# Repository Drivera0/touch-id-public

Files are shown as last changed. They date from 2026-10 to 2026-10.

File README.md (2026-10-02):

# Whorl Touch: a fingerprint knob for the NuPhy Air75 V3

A drop-in fingerprint-authentication module that replaces the knob in the
top-right corner of a **NuPhy Air75 V3**. Touch it and it confirms your identity
to the paired computer wirelessly, without a $149 Touch ID keyboard.

> [!WARNING]
> **Work in progress.** The design is finished on screen, but nothing has been
> proven on real hardware yet. The main PCB hasn't been ordered or built yet,
> the firmware hasn't been built or run on the board, and none of it has been
> tested end to end. See [Project status](#project-status) for exactly where
> things stand.

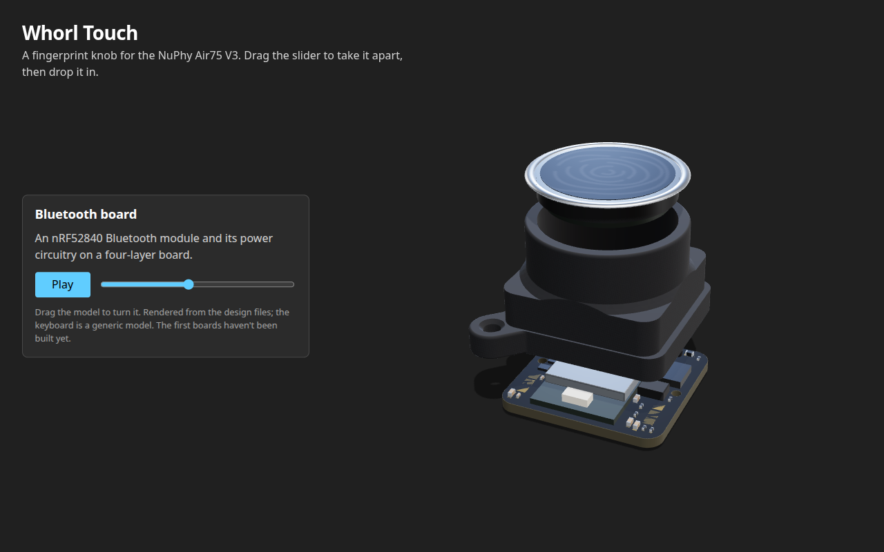
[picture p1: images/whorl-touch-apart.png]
Whorl Touch taken apart, from the interactive 3D model


**[Open the interactive 3D model](https://drivera0.github.io/whorl-touch-public/)**:
drag to turn it, slide to take it apart
([or open it already apart](https://drivera0.github.io/whorl-touch-public/?at=0.45)),
then watch it drop into the keyboard.

This repo is the project's public face: the story of how it was designed, and
a 3D model of the module. **[JOURNEY.md](JOURNEY.md)** tells the story; the
design files themselves are private.

## The problem

- The Air75 V3 runs NuPhy's closed firmware (no QMK), so the keyboard can't be
  taught about a sensor. The module is an **independent sidecar**: it uses the
  knob slot as a mount and does its own sensing, crypto and radio.
- The slot supplies **no power**, so the module harvests its own energy and
  runs from a protected 77 mAh coin cell.
- The board is a small 4-layer design around an nRF52840 module, with a
  fingerprint sensor above it in a printed nylon housing.

## Project status

*Last updated September 2026.*

```mermaid
flowchart TB
  subgraph S1["1 · Design"]
    direction LR
    A["Research &<br/>teardown"] --> B["Architecture"] --> C["PCB design<br/>v2 → v7"] --> E["Fab package"]
    D["Housing design"] --> F["Housings<br/>printed"]
  end
  subgraph S2["2 · Build"]
    direction LR
    G["Flashing<br/>fixture"] --> H["Main PCB made<br/>& assembled"] --> I["Bring-up &<br/>power tests"]
  end
  subgraph S3["3 · Prove it works"]
    direction LR
    J["Firmware on<br/>real hardware"] --> K["Fingerprint match<br/>end to end"] --> L["Mac / Windows<br/>helper apps"]
  end
  subgraph S4["4 · Next"]
    direction LR
    M["USB dongle"]
  end
  S1 --> S2 --> S3 --> S4

  classDef done fill:#2da44e,stroke:#1a7f37,color:#fff
  classDef doing fill:#d4a72c,stroke:#9a6700,color:#000
  classDef todo fill:#eaeef2,stroke:#8c959f,color:#24292f
  class A,B,C,D,E,F done
  class G doing
  class H,I,J,K,L,M todo
```

Green = done, yellow = in progress, grey = not started.

| Stage | Status | Notes |
|---|---|---|
| Research and keyboard teardown | Done | Every slot contact characterised by measurement (method and results private) |
| Architecture | Done | Independent sidecar, harvests its own energy, protected coin cell |
| PCB design | Done (on screen) | v7 passes all 22 pre-order checks and DRC. Never built. |
| Housing | Printed | Both housing variants printed in MJF nylon and look good. Not yet fitted with a real board. |
| Fab package | Ready | Gerbers, BOM and placement verified against each other |
| Flashing fixture | In progress | The first printed pogo-pin jig failed, so it's being replaced by a custom carrier PCB and a 3D-printed flash frame. |
| Main PCB | Not ordered yet | Design and fab files are ready; it gets ordered once all the parts are in hand |
| Bring-up and power tests | Not started | Needs a built board |
| Firmware | Not started on hardware | Architecture and protocols are designed. The firmware hasn't been built for or run on a real board. The source is closed; see [firmware/](firmware/README.md). |
| Fingerprint matching end to end | Not started | |
| Host apps (Mac / Windows) | Prototype | Early helper-app experiments; not tested with a real module |
| USB dongle | Design study | Size and module trade studies done |

## What's here

| Path | What's in it |
|---|---|
| `JOURNEY.md` | How the design got built, milestone by milestone |
| `docs/` | The interactive 3D model, served by GitHub Pages |
| `firmware/` | A pointer: the source is closed, binaries come as Releases |
| `THIRD-PARTY-NOTICES.md` | Credits and licences for third-party work |

## Not in this repo

The files needed to build the product are private:

- Board source and fab files, board renders, and the flashing fixture
- The keyboard-slot work: how it was mapped, what each contact carries, the
  measurements and the design docs that record them
- The housing and board generators, and the engineering notes and design docs
- Firmware and helper-app source code
- Vendor datasheets (copyrighted), supplier quotes and contact details

## Tools

KiCad 10, Altium (cross-check), CadQuery, Python, Zephyr on nRF52840,
JLCPCB PCBA and MJF nylon printing.

## Credits and license

Inspired by [tinyTouch](https://github.com/ZimengXiong/tinyTouch) by Zimeng Xiong and by
[YubiKey](https://www.yubico.com/products/).

Everything else: **© 2026 Driver. All rights reserved.** You're welcome to
read it and learn from it. Please ask before reusing it.

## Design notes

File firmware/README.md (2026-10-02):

# Firmware

The firmware for the knob (Zephyr RTOS on the nRF52840) is **closed source**
and isn't in this repository.

- **Prebuilt firmware** will be published as `.hex` files under this repo's
  [Releases](https://github.com/Drivera0/whorl-touch-public/releases) once it has run on real hardware. Each release
  includes `SHA256SUMS` so you can check the download.

Status: not yet built for or run on a real board. See
[Project status](../README.md#project-status).

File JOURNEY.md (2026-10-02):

# The journey: how the board got built

> **Still a work in progress.** Everything below is design work. The board
> hasn't been manufactured or tested yet, and the firmware hasn't run on real
> hardware. See [Project status](README.md#project-status).
>
> The design files, board renders and keyboard-slot measurements stay
> private. Every commit is here with its message, but without the private
> files, and messages that would give away the slot contacts are reworded. The module is public as an
> [interactive 3D model](https://drivera0.github.io/whorl-touch-public/).

How the design got built, milestone by milestone. Each milestone is a
[git tag](https://github.com/Drivera0/whorl-touch-public/tags); click a commit
to read its message.

Whorl Touch taken apart, from the interactive 3D model

---

## 1. Salvage the first board (Aug 20): `m01` → `m02`

The first design was an ESP32-C3 board drawn in Altium. Before changing
anything, it got imported into KiCad and checked against the original.

- [Import the Altium board into KiCad, verified exact](https://github.com/Drivera0/whorl-touch-public/commit/c0a0e6f)
- [Nine orphan `)` made the board file unparseable](https://github.com/Drivera0/whorl-touch-public/commit/6b71473), so a syntax gate was added and has run on every edit since
- [Every land pattern traced back to its vendor drawing](https://github.com/Drivera0/whorl-touch-public/commit/d55f322), which found errors on U1, U2 and C3/C4

**Lesson:** a footprint you haven't traced to a datasheet is a guess.

## 2. The master spec and the v3 rebuild (Aug 26 – 27): `m03` → `m05`

The ESP32 was too wide for the slot. The rebuild moved to a BLE-only nRF52840
module on a 4-layer board, and one design spec became the single source of
truth (it stays private).

- The design spec becomes the master file
- [pcb-v3 built: 4 layers, 177 pads, all three checkers pass](https://github.com/Drivera0/whorl-touch-public/commit/d357334)
- [Two checker bugs, including KiCad's Y-down rotation sign (79 phantom shorts)](https://github.com/Drivera0/whorl-touch-public/commit/fc8540c)
- [U2's land was 0.25 mm off its own centreline](https://github.com/Drivera0/whorl-touch-public/commit/b953dad)
- [The "open connections" metric was lying](https://github.com/Drivera0/whorl-touch-public/commit/37f3c16). A net with zero copper never showed as disconnected, so deleting a net scored as a win.
- [Zero open connections, 15/15 preflight checks](https://github.com/Drivera0/whorl-touch-public/commit/84c035e)

**Lesson:** when a check fails, suspect the checker first. It was wrong more
often than the board.

## 3. "The board had no ground" (Aug 28): `m06` → `m07`

- [THE BOARD HAD NO GROUND](https://github.com/Drivera0/whorl-touch-public/commit/1692c54). Every check passed, and none of them looked for it. The ground pour went in, and a gate was added so it can't happen again.
- [KiCad 10 changed the file format and every parser went blind](https://github.com/Drivera0/whorl-touch-public/commit/eca1690)
- Altium's DRC found a real defect the KiCad checks couldn't see. The board was then re-imported clean.
- [The pick-and-place file was in the wrong coordinate space](https://github.com/Drivera0/whorl-touch-public/commit/34131c6)
- A housing corner wall was 0.15 mm, not 0.8

**Lesson:** cross-check with a second, independent tool.

## 4. Choosing the cell (Aug 28): `m08`

The module needs stored energy, and nothing that fits the cavity is simple.

- [The CP1254 "IP Wires" is not protected and doesn't fit](https://github.com/Drivera0/whorl-touch-public/commit/47fa22a)
- [The charge limit is 4.30 V, not 4.00 (a misread footnote)](https://github.com/Drivera0/whorl-touch-public/commit/97d280d)
- [Cell decided: LiPol LPM1254 with a factory PCM and wires](https://github.com/Drivera0/whorl-touch-public/commit/689705c)
- [Sensor: the ZW0905 was discontinued; the HLK-ZW0922 is a drop-in](https://github.com/Drivera0/whorl-touch-public/commit/5e64939)

## 5. The long routing fight (Aug 29 – 30): `m09` → `m10`

Adding a protection IC to a 20 × 19 mm board started two days of placement,
routing and ground-pour work.

- [My "it doesn't fit" result was a fourth scanner bug](https://github.com/Drivera0/whorl-touch-public/commit/935eb35)
- Slot depth was never a constraint: the module stands proud by design
- Reverted three hand-placed ground taps, all of them faulty
- [pour_truth.py judges connectivity against the fill KiCad actually computed](https://github.com/Drivera0/whorl-touch-public/commit/8d3021e), not a model of it
- [Both press-fit pins had been drilled through copper](https://github.com/Drivera0/whorl-touch-public/commit/9170b3f)
- [Custom pads: `(size)` is the anchor, not the copper, so every parser read 3× low](https://github.com/Drivera0/whorl-touch-public/commit/6880130)
- [Rejected a smaller module (BC840M), because it needs a larger board](https://github.com/Drivera0/whorl-touch-public/commit/a3a3f36)
- v5: DRC clean, then [v6: zero open pads, zero blockers](https://github.com/Drivera0/whorl-touch-public/commit/0410f94)

**Lesson:** a smaller part isn't always a smaller board. Ceramic-antenna
modules need less keep-out than trace-antenna ones.

## 6. v7 and release (Aug 31 – Sep 1): `m11` → `m13`

- [The protected cell was confirmed, so the on-board PCM was deleted](https://github.com/Drivera0/whorl-touch-public/commit/946cf8b). That removed four parts and healed the last stranded pad.
- `m11`: preflight at 0 blockers, 0 open pads, ground fully connected. The v7 board files are private.
- [Pogo-pin flashing jig](https://github.com/Drivera0/whorl-touch-public/commit/e7efebc)
- [Housing v6.5 after JLC's DFM review](https://github.com/Drivera0/whorl-touch-public/commit/0dcda58)

## 7. Firmware and the product direction (Aug 31 – Sep 1)

The firmware history is merged in: Zephyr on the nRF52840, the sensor driver,
the auth crypto and the helper apps. The design docs and the source
code stay private.

- [Gut the ESP32 fork and start the nRF52840 Zephyr firmware for pcb-v7](https://github.com/Drivera0/whorl-touch-public/commit/d6a3725)
- [LESC-only pairing, HMAC challenge-response and a hash ratchet](https://github.com/Drivera0/whorl-touch-public/commit/f7243ab)
- [Mac keycard proven: `sudo` authenticates by smart card, gated on a touch](https://github.com/Drivera0/whorl-touch-public/commit/2de955a)
- [A smart card you can't remove is a lockout, so that got fixed](https://github.com/Drivera0/whorl-touch-public/commit/2353bb1)
- [Knob-to-dongle transport: proprietary 2.4 GHz (ESB), not BLE](https://github.com/Drivera0/whorl-touch-public/commit/f0d7535)
- [Product pivot: FIDO2 is the core of the product](https://github.com/Drivera0/whorl-touch-public/commit/5d12048)

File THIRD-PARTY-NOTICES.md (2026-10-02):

# Third-party notices

Whorl Touch includes or credits the work below. Each release ships this file.

## tinyTouch

Whorl Touch was inspired by tinyTouch (https://github.com/ZimengXiong/tinyTouch).
Its notice is included here as a courtesy and so that any question is settled.

```
MIT License

Copyright (c) 2026 Zimeng Xiong

Permission is hereby granted, free of charge, to any person obtaining a copy
of this software and associated documentation files (the "Software"), to deal
in the Software without restriction, including without limitation the rights
to use, copy, modify, merge, publish, distribute, sublicense, and/or sell
copies of the Software, and to permit persons to whom the Software is
furnished to do so, subject to the following conditions:

The above copyright notice and this permission notice shall be included in all
copies or substantial portions of the Software.

THE SOFTWARE IS PROVIDED "AS IS", WITHOUT WARRANTY OF ANY KIND, EXPRESS OR
IMPLIED, INCLUDING BUT NOT LIMITED TO THE WARRANTIES OF MERCHANTABILITY,
FITNESS FOR A PARTICULAR PURPOSE AND NONINFRINGEMENT. IN NO EVENT SHALL THE
AUTHORS OR COPYRIGHT HOLDERS BE LIABLE FOR ANY CLAIM, DAMAGES OR OTHER
LIABILITY, WHETHER IN AN ACTION OF CONTRACT, TORT OR OTHERWISE, ARISING FROM,
OUT OF OR IN CONNECTION WITH THE SOFTWARE OR THE USE OR OTHER DEALINGS IN THE
SOFTWARE.
```

## KiCad routing tools

`tools/com_github_drandyhaas_kicadroutingtools` is © drandyhaas, MIT
licensed; its full text is in that folder's `LICENSE`.

## Still to list before the first release

The libraries built into the firmware and apps (Zephyr and MCUboot under
Apache 2.0, Nordic nrfx under BSD-3-Clause, the .NET runtime under MIT,
and each app's packages), each with its licence text.

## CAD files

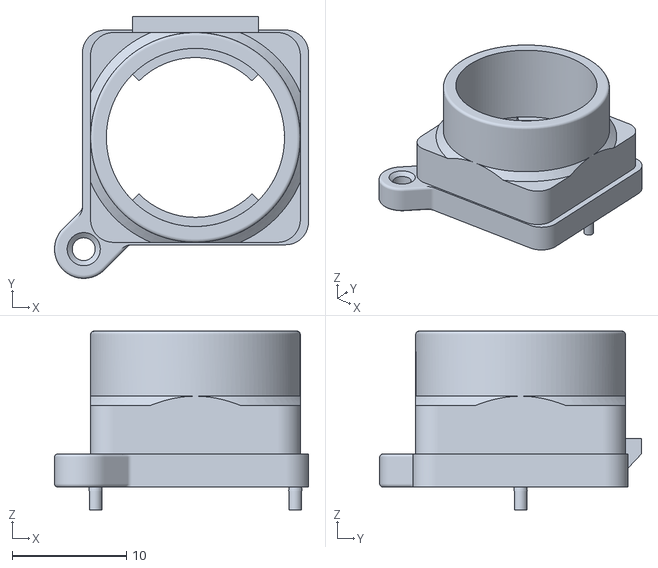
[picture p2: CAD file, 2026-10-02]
docs/housing.stl
22.2 x 22.9 x 15.7

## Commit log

2026-08-20 Baseline: TouchID module as it stands before the U2 land pattern fix
    State captured here:
    cad/pcb-initial-failure/ the design that went to JLCPCB as order [order #] / Y6.
    gerbers-as-ordered/ is MD5-identical to the files JLCPCB received.
    U1 (ESP32-C3-MINI-1) land pattern is CORRECT: 61 pads, 48 perimeter on
    0.8 mm pitch, 1.45 mm thermal grid, 0.7 mm corners, antenna oriented
    away from the pogo pads.
    U2 (TPS7A2033, X2SON-4) land pattern is WRONG: signal pads at
    +/-0.520/+/-0.520 instead of +/-0.421/+/-0.325, thermal 0.55 unrotated
    instead of 0.48 rotated 45 deg, and no solder mask dam.
    cad/pcb-v2/ byte-identical copy of the above, the working f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
2026-08-20 Import the Altium board into KiCad, verified exact
    KiCad 10 File > Import > Non-KiCad Board File on pcb-v2.PcbDoc, saved as
    pcb-v2.kicad_pcb. Layer mapping auto-matched except Edge.Cuts, which
    auto-match sent to Margin; corrected to Edge.Cuts by hand.
    Import result: 96 pads, 184 track segments, 15 vias, 9 nets, 0 unrouted.
    Two footprints: touchid:touchid_board and Espressif:ESP32-C3-MINI-1, so U1
    is a real component with pads 1-53 rather than loose copper.
    VERIFICATION: every one of the 80 SMD pads in the ordered Gerber's top paste
    layer has an exact counterpart in the imported board, max position error
    0.0000 mm, under the transform recorded in cad/pcb-v2/COORDINATE-MAP.txt.
    The importer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
2026-08-20 Fix U2 land pattern (TPS7A2033DQNR, LCSC C46459900, X2SON-4)
    The single real defect on the ordered board. Five pads edited, nothing else
    touched: no tracks, vias, other pads or footprints changed.
    before after
    U2-1..4 0.30 x 0.30 at +-0.520 0.36 x 0.30 at +-0.421 / +-0.325
    U2-5 0.55 sq, no rotation 0.48 sq, ROTATED 45 deg
    all five solder_mask_margin 0 solder_mask_margin -0.05
    Geometry from JLCPCB/LCSC's own footprint for C46459900, cross-checked
    against TI package drawing DQN0004A 4215302/E. Coordinates converted through
    the Y-mirror recorded in COORDINATE-MAP.txt.
    VERIFIED after the edit:
    positions all five land e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
2026-08-20 WIP: U2 pads moved, local routing NOT yet corrected - board has a short
    DO NOT PLOT GERBERS FROM THIS COMMIT.
    Contains:
    - U2 land pattern corrected (commit 98c9e5e, verified correct)
    - U1 pin 5 (GPIO2) tied to +3V3 by a 0.668 mm stub, 0.473 mm clearance, OK
    - check_board.py, a geometry checker that honours pad SHAPE
    KNOWN BROKEN: moving U2's pads by ~0.2 mm left the existing tracks where they
    were, drawn to the old pad positions. Result:
    SHORT U2-1 (+3V3) touching a GND track 0.0000 mm
    tight U2-5 (GND) vs a VBAT track 0.0970 mm
    tight U2-3 (VBAT) vs a GND track 0.1140 mm
    The escape corridors around a 1x1 X2SON are under 0.5 mm, so the local tracks
    need re-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
2026-08-20 Re-route U2's escape for the new pad positions; short resolved
    Deleted 9 tracks that were drawn to U2's OLD pad centres and replaced them
    with 7 at 0.15 mm, which is what fits the escape corridors around a 1x1
    X2SON. The 0.254 mm board default physically does not: the gap between
    U2-1 and U2-4 is 0.482 mm and a 0.254 track needs 0.508 mm with clearance.
    GND U2-5 south escape between U2-1 and U2-4, then to the existing net
    GND U2-2 to U2-5, and U2-2 west to the existing GND branch
    VBAT in to U2-3, down to U2-4 at x=141.46 clear of the U2-5 diamond,
    back out to the VBAT branch
    +3V3 in to U2-1
    RESULT
    before: SHORT U2-1(+3V3) to a GND track 0.0000, plus 0.0970 and 0.114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
2026-08-20 Route U1-22 (GPIO8) to +3V3; both strapping pins now tied high
    GPIO8 had no +3V3 within 4.648 mm and needed a real route, unlike GPIO2 which
    had a 0.668 mm stub available. Written a grid router (route_one.py) rather
    than eyeballing coordinates: it builds an obstacle map from the real copper
    honouring pad SHAPE, inflates by clearance + half trace width, and A*-searches
    F.Cu/B.Cu with vias. It returns nothing rather than something illegal.
    Route: 4 segments at 0.15 mm + 3 vias, pin 22 -> B.Cu -> F.Cu -> B.Cu -> the
    +3V3 branch near (145.45, 105.05). Three vias because B.Cu is genuinely
    blocked between y 102.7 and 104.95 at that x; raising the via cost from 0.6 to
    3.0 did not reduce it, which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
2026-08-20 Repair 9 orphan ')' that made the board file unparseable; add a syntax gate
    Found while saving the board: the file had 9 more closing parens than opening
    ones. KiCad would have refused to open it, and it would never have plotted.
    Cause: my track deletion in bd6b0d5 (the U2 re-route) removed each segment
    block's contents but left its final ')' behind, 9 times. Introduced there,
    not by the pin 22 route.
    Why nothing caught it: check_board.py and check_connect.py both read the board
    with REGEX. Regex finds the blocks it is looking for and ignores everything
    else, so both kept reporting a clean, fully connected board. Every clearance
    and connectivity number they printed was correct. The file wa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
2026-08-20 Add HANDOFF.md; commit the JLCPCB production file and the routing/check scripts
    HANDOFF.md covers cad/pcb-v2 only: what is fixed, what is open and ranked, the
    coordinate transform, the verification workflow, and the eight traps that have
    each produced a confident wrong answer at least once.
    New finding from diffing against production-file-old-version.zip: U1's chamfered
    thermal pad is misplaced by exactly (1.45, 1.45) in the KiCad import. The ordered
    Gerber puts a chamfered 1.45 square at the 9th grid slot; the KiCad file has a
    0.8x0.8 there and the chamfered polygon 1.45 mm away, overlapping the centre.
    All GND so no short, but the artwork would not match. Total thermal copper is
    18.7069 v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
2026-08-20 Trace every land pattern to its vendor drawing; fix U1 pad 49, U2, C3/C4
    U1 pad 49: the Altium->KiCad import split Espressif's chamfered thermal into
    a 0.8x0.8 rect at the correct slot plus the 1.45 chamfer polygon offset
    (1.45, 1.45) on F.Cu only. Rebuilt as one custom pad on Cu+Mask+Paste; the
    detached island is deleted. Global bbox and cut corner now match the Y6 G36
    region exactly. Recovers 1.28 mm2 of solderable area.
    U2: the previous fix read TI 4215302/E's LAND PATTERN EXAMPLE dimensions as
    copper. That sheet is SOLDER MASK DEFINED, so 0.36/0.21/0.48 are mask
    openings. Copper is now 0.46 x 0.31 chamfered at (+/-0.43, +/-0.325), mask
    0.36 x 0.21, thermal 0.58 diamond / 0.48 mask / 0.4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
2026-08-20 Square the board, go diagonal on the screws, drop the stale Altium files
    Outline -> 19.30 x 19.30 R2.0 (was 19.60 x 17.60). Gives up 0.30 in X to gain
    1.70 in Y, which is the starved axis - U1's body is 16.6 of a 17.6 board.
    Mounting holes -> O1.30 on one diagonal, matching the v4 housing's M1.2
    bosses. Diagonal, as asked. The other diagonal is impossible: a pogo pad
    occupies one of its corners and its position is set by the keyboard.
    C3 and C4 moved in Y so the corner hole clears C4-1.
    16 board-edge keepouts deleted - they were an artifact of the original Altium
    import and Altium enforces edge clearance by design rule. The 2 antenna
    keepouts are kept and extended into the new space.
    12 s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
2026-08-20 Move the v4 housing next to the board; log the Altium import attempt
    Copied touchid_housing_v4_diagonal.stl/.step, the ZW0905 assembly and the
    matching PCB blank into cad/pcb-v2 so the mechanical and electrical sources sit
    together. The old housing STL is renamed *_OLD-superseded.stl.
    Altium import attempted. The import itself works - File > Import Wizard > KiCad
    Design Files, add pcb-v2.kicad_pro. Analysis: 0 ERRORS, 572 warnings, all of
    them benign 'Unknown child uuid/tenting/covering of setup' (KiCad 10 keywords
    the importer does not know). 0 errors was impossible before the net-schema fix.
    Blocked at the layer-mapping page: Altium reads every KiCad layer as
    'Conductive Layer' and propo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
2026-08-27 Save point before the v3 rebuild
    Session of 2026-08-27. Everything measured and decided so far:
    - Slot measurements taken. Wired vs wireless is irrelevant. Ground-path
    control test passed clean, so the numbers are real.
    - ZW0905 datasheet obtained: 3.0 V min, 10 uA standby, 25 mA active.
    Pinout in DESIGN-SPEC was the ZW0901's and is now corrected.
    - Storage must be a cell (CP1254); supercaps ruled out on three counts.
    - Housing gains a 4.50 mm riser, which is what makes the cell fit.
    Next session rebuilds the housing, schematic and board.
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2026-08-27 Task C: spacebar edge is board +Y, resolved from the file; fix DESIGN-SPEC §1
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2026-08-28 Fix the KiCad freeze: GND pours read as board-wide obstacles; route first, pour last. Add ROUTING-SETTINGS.md
2026-08-28 pcb-v3: fix the two routing root causes (43 dead module pads sealing the ring; area-only packing at 0.34mm). Add check_escape.py gate. 14/27 -> 23/27 nets, but router still escalates below the fab fl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
2026-08-28 pcb-v3: honest routing results. Router ignores --layers and puts signal copper on the In2 plane (tool bug). U2's 4 stuck pins are structural: 0.26mm pad gaps, 0.21mm ring, via-in-pad impossible at 0.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
2026-08-28 pcb-v3: silkscreen (F.Fab designators, pin-1 dots, back identity block). Fix two checker bugs: KiCad Y-down rotation sign (79 phantom shorts) and rule-area layer scoping (47 phantom boxed pads). All 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
2026-08-28 pcb-v3: re-source footprints from JLCPCB (L1 0.96->2.20mm was badly wrong), keep TI's land for U2 where JLC's is wider and riskier. Remove name from silk, add connector pinout labels + pin-1 dots.
2026-08-28 housing: sync mcu_center 0.90 -> 1.00 to match the board (0.10mm drift); all 8 boolean checks pass. L1 land corroborated against the 252012 datasheet terminal width. Add footprint provenance ledger.
2026-08-28 3D: board_3d.py builds a dimensionally real assembly from JLCPCB body sizes and boolean-checks it against housing v5 -- no collisions. Sync housing mcu_center to the board.
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2026-08-28 U2 land was 0.25mm off its own centreline (even-count offset formula for an odd pad row). LX wrapped 11mm around the chip; L1 moved above U2 and flipped -> 1.91mm. Opens 8->7.
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2026-08-28 ZERO open connections: 15/15 preflight checks pass
    Four causes, not one:
    - test points placed decoratively in a row instead of by net locality
    (and polluting every net centroid, dragging the passives with them)
    - parts sitting on pogo pads, where a through-hole via would come out
    through the mating contact
    - CHAN still reserving 0.60mm channels sized for the retired 0.20 rule
    - net ORDER: OK_PROG took the one-track corridor east of U2 and ran 10mm
    up the board edge, walling VBAT_OK's pin in. Rip the squatter, re-route
    it after the pin it starved.
    Also fixes four checkers that were lying: preflight used a relative board
    path under cwd=KRT, check_board hard-coded 0.127, the ha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
2026-08-28 Document bottom-face copper exposure; keep TP9/TP10
    Removing the two spare GND test points broke the routing (0 opens -> 4,
    best recovery 3): the placement that routes cleanly is not robust to small
    perturbations. The premise was also wrong -- they are GND, the safest net
    to expose on the mating face. VSTOR/VBAT/VIN_DC are the ones that matter.
    Insertion confirmed straight-down, which eliminates the pogo-sweep short
    (a slot pin dragging across exposed powered copper on every insertion).
2026-08-28 Close B6/BT1/C7 — and fix an overcharge bug found on the way
    B6b (NEW, the serious one): VBAT_OV was 4.246 V from ROV1/ROV2 = 5.6M/7.5M,
    against a CP1254 A4 rated 4.00 +-0.05 V max charging voltage. 246 mV over the
    cell limit, and its worst case (4.295 V) sat ON the 4.30 V over-charge trip of
    the PCM B6 adds -- making the safety device the working regulator, which the
    CoinPower handbook explicitly warns against. Now 6.04M/6.98M = 3.912 V nominal,
    3.955 V worst case. Costs ~10% capacity, buys cycle life. No geometry change:
    the board file carries no value fields.
    B6: MEASURED that no PCM can go on this board -- 9.1% of the top layer is free
    and NONE of it can take a via (every gap is over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
2026-08-28 THE BOARD HAD NO GROUND. Pour GND, weld all 40 pads, gate it forever
    Found while auditing: 40 GND pads, 0 GND tracks, 0 GND vias, 0 filled zones.
    The board was inert. It passed 17/17 preflight checks and '0 open connections'
    the whole time, because check 6 excludes GND by name -- during routing an
    unpoured GND is expected, and the pour is a separate later step that was never
    run. A gate that cannot see a missing ground plane is not a gate.
    Now: GND poured on F.Cu/In2.Cu/B.Cu (3 filled zones) plus 15 stitching taps
    welding every pad to the plane. check_connected: ALL NETS FULLY CONNECTED.
    DRC: NO VIOLATIONS.
    gnd_taps.py places the taps deterministically because route_planes places none
    and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
2026-08-28 Full sweep: 3 more found in the zone blind spot, + thermal relief
    The missing ground plane was not a one-off -- ZONES were a category the gate
    could not see, and two more were sitting in the same place.
    1. Zones carry NO filled_polygon. check_connected models the fill and says
    'all nets connected' from the outline alone, but a PLOT of an unfilled
    board has no plane on it -- the original bug, one step further along.
    check 18 blocks until the fill is materialised in KiCad.
    2. Board thickness was never declared. No (stackup) at all, and thickness is
    invisible to every 2D check. housing v5 needs 1.20mm; KiCad and JLCPCB both
    default 4-layer to 1.60mm -- 0.40mm too thick for its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
2026-08-28 KiCad 10 changed the file format and my parsers went blind
    Filling the zones round-tripped the board through KiCad 10, which writes a NEW
    format: the top-level (net N "NAME") table is GONE and every item now carries
    (net "NAME") directly. sexp.pads() read index [2] and returned 134 pads with
    ZERO nets. A checker that sees no nets passes everything -- the most dangerous
    possible failure, and it would have reported a clean board.
    (KRT's own checkers were fine: they print 'Checking 27 routed nets'.)
    Fixed sexp.net_of()/net_table() and every preflight pattern to accept BOTH
    formats, then re-ran and found two things the blind version had hidden:
    REAL: a GND tap via at (-5.20, 4.70) put 0.05mm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
2026-08-28 VBAT needs no fix; check 10 now measures IR drop, not width
    Measured: VBAT is 67.8 mOhm over its longest path (BT1.1 -> U2.18) = 14.2 mV
    at 210 mA, the CP1254's own max pulse rating. The cell's ~0.5 ohm ESR drops
    105 mV at that same current -- 7.4x the whole trace. Widening to 0.40mm buys
    ~7 mV against a drop inherent to the cell. 0.2mm 1oz carries well over 1A vs a
    0.21A peak. No board change.
    Check 10 rewritten from 'has a 0.40mm trunk' (a proxy) to 'IR drop <= 25 mV at
    documented peak current' (the actual question), with currents cited from the
    design docs rather than invented.
    It grades ONLY the nets it can trace end to end. The graph is
    endpoint-and-overlap based; real connectivity is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
2026-08-28 v4: Altium cross-check package
    v4 is NOT a redesign -- it is the verified v3 board, frozen, for an independent
    look by a mature DRC. KiCad stays the master; fixes land there and re-export.
    Ships BOTH formats because Altium's KiCad importer predates KiCad 10's format,
    and we already know that format change made this project's own parsers read 134
    pads with ZERO nets. If the importer half-understands the file, Altium's DRC
    checks a board that is not ours and a clean report means nothing.
    touchid-v4.kicad_pcb KiCad 10, zones filled (try first)
    touchid-v4-kicad9format.kicad_pcb KiCad 9, unfilled (fallback)
    Verified identical copper: 46 fp / 134 pads / 124 netted / 459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
2026-08-28 Altium import done: nets and parts exact, layers OK on the fallback ONLY, stackup dropped
    The KiCad 10 file imports WRONG and silently: Altium mapped B.Cu->Mid Layer2,
    Edge.Cuts->Mid Layer25, F.CrtYd->Bottom Layer -- by index order, not meaning.
    The outline became a copper layer. Its log said 'errors: 0'. A DRC on that
    would have been meaningless while looking like a clean import. This is exactly
    the risk the two-file package was built for.
    The KiCad 9 fallback maps correctly (Top/Mid1/Mid2/Bottom, masks, overlays,
    pastes, Edge.Cuts->Keep Out).
    Fidelity verified through the MCP bridge:
    nets 27 expected -> 27, exact name-for-name match
    components 46 expected -> 46
    layers 4,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
2026-08-28 Altium DRC: 0 warnings, 1 violation -- and it found a real defect I could not see
    Set Width min to 0.127 first (Altium imported its 10-mil default, 0.254, which
    would have flagged every trace). Clearance came across correctly at 0.10.
    Repoured the 3 polygons.
    Result: clearance 0, short-circuit 0, UN-ROUTED NET 0, width 0, hole size 0,
    hole-to-hole 0, mask sliver 0, silk 0. One violation: Net Antennae.
    That one is REAL and it is mine. A GND stub (+7.400,+6.900)->(+7.550,+7.050):
    far end on a GND via, near end touching NOTHING -- no track, via or pad.
    gnd_taps' endpoint-snapping pass detached a tap from its pad. Harmless
    electrically (the F.Cu pour covers it, check_connected still sees every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
2026-08-28 Fix the dangling stub Altium found; add check 20 (free track ends)
    Removed the GND antenna at (+7.400,+6.900)->(+7.550,+7.050). All nets still
    connected, DRC still clean.
    check 20 added, and it took three corrections to become trustworthy -- worth
    recording because each was a way of being WRONG about copper:
    - an axis-aligned pad test invented 12 free ends where 1 existed (rotated and
    custom pads need the circumscribed circle)
    - ignoring the POUR made 6 of those stick: an end inside its own net's fill is
    connected, and a gate that cries wolf gets ignored
    - testing the centre POINT instead of the COPPER flagged VREF_SAMP, whose
    trace ends 0.010mm outside U2.4's pad rectangle whil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
2026-08-28 Altium re-import after the fix: 0 warnings, 0 rule violations
    Fresh import of the corrected board, width rule 0.127 on all four layers,
    polygons repoured, DRC re-run. Every rule zero including Net Antennae.
    KiCad and Altium now agree on every class of check either can see:
    clearance, shorts, width, holes, mask, connectivity, and free track ends.
2026-08-28 Flag the stale BOM/CPL as poison, and record what JLC actually needs
    cad/exports/fingerprint module-{BOM,CPL}.csv are from 19 Aug and describe the
    DEAD ESP32 board: U1=ESP32-C3-MINI (now MDBT50Q), U2=TPS7A2033 (U2 is now the
    BQ25505 charger), 4 BOM lines vs ~30 parts, coordinates on a different origin.
    Uploading them would place the wrong parts at the wrong places.
    Also recorded that JLC needs no 3D models: BOM (designator -> LCSC) + CPL
    (designator, X, Y, rotation, layer). It knows the physical part from its own
    library keyed by LCSC number. Our 3dmodels/ are for the housing check only.
    Two hazards named: JLC's rotation convention differs from KiCad's per package
    (classic 90/180 error), a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
2026-08-28 Generate the real BOM and CPL; archive the poisonous ones
    make_bom_cpl.py builds both from the routed board:
    CPL 29 parts, all Top, origin moved to the board's lower-left with Y
    flipped (X = x+9.65, Y = 9.65-y). Verified by re-deriving all 29 rows
    from the board file: 0 mismatches, U1 lands where the housing's
    mcu_center says it should, nothing outside the outline.
    BOM 21 lines, grouped by value.
    The BOM does NOT invent part numbers. 20 of 21 lines carry an explicit
    'SOURCE THIS' marker, because we genuinely only have one traced LCSC number
    (U1, C5118826). The 0402/0603 references in PART-LIBRARY are LAND derivations
    -- they prove the pad geometry, they are not a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
2026-08-28 Add a plain-language assembly guide
    Carries the warnings that matter to someone building it for the first time:
    verify the sensor pinout against its own datasheet (this table was previously
    WRONG, copied from a different model and reversed), attach the cell last so the
    board can be tested with no stored energy on it, and never wire a bare
    unprotected lithium cell (B6).
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2026-08-28 Verify everything and package cad/v3-handoff/ (gerbers still to come)
    Four checkers over the board, the housing, the BOM and the CPL, then a
    handoff folder of COPIES -- originals stay where the build scripts expect
    them, with SHA256SUMS proving the copies are what was graded.
    sexp_check parses, 46 fp / 134 pads / 458 segs / 65 vias
    preflight 21 checks, 0 blockers, 2 known warnings
    verify_handoff 13 checks, 0 failures (NEW)
    verify_sourcing 25/25 lands match the package bought
    touchid_module_v5 8/8 booleans = 0.0000 mm^3
    verify_handoff.py is new and exists because make_bom_cpl.py grading its own
    output proves nothing. It re-derives the JLC origin tran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
2026-08-28 Plot the gerbers, verify them against the board, package the JLC zip
    11 gerbers + PTH/NPTH Excellon + job file, plotted from KiCad 10 and zipped as
    cad/v3-handoff/touchid-v3-jlcpcb.zip. New verify_gerbers.py grades the OUTPUT
    against the BOARD -- 12 checks, 0 failures:
    67 drill hits vs 67 board holes, diameters {0.30: 65, 1.30: 2} both sides
    outline 19.300 x 19.300 read back out of Edge_Cuts.gbr
    no layer silently empty: F 3631 / In1 158 / In2 2462 / B 3298 draws
    all 11 layers metric, 4.6, positive image, unmirrored
    The empty-layer test is the point of the file. A missing plane produces a
    valid-looking gerber with a header and no geometry, and nothing else in this
    project would catc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
2026-08-28 JLCONE quote filled and left ready: 5 boards
    Not ordered -- stopped before Save to Cart, checkout is the user's.
    Uploading touchid-v3-jlcpcb.zip made JLCPCB's OWN gerber parser read 4
    layers and 19.3 x 19.3 mm directly off the files. Both fields set
    themselves, which is better evidence the export is correct than any check
    I wrote: an independent tool reconstructed the board from the gerbers
    alone. Only thickness (1.2 mm) and finish (ENIG) had to be chosen by hand
    -- they are not in the gerbers.
    Everything else was already right at JLC's 4-layer defaults, and two of
    those are worth not disturbing: 1 oz outer / 0.5 oz inner IS the board's
    declared 0.035 / 0.0152 mm stackup, and min via 0.3 m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
2026-08-28 CPL was in the wrong coordinate space -- fix it and check it against the gerber
    JLCPCB's placement viewer caught a real defect: it drew every component
    floating off the board and offered to 'automatically align' them.
    The CPL was corner-based (0..19.30). The gerbers were plotted with 'use
    drill/place file origin' OFF, so they carry the board's native KiCad
    coordinates, CENTRED on (0,0), spanning -9.65..+9.65. A pure 9.65 mm offset in
    both axes. Either convention is fine on its own; what is not fine is the two
    disagreeing, because the fab has nothing else to align the CPL against -- and
    the failure mode is not one bad part, it is EVERY part off by the same amount.
    Transform is now just the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
